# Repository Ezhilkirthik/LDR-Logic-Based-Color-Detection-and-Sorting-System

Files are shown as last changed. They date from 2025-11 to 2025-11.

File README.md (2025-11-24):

# LDR-Logic-Based-Color-Detection-and-Sorting-System
LDR Logic-Based Color Detection and Sorting System. Microcontroller-free automation using Analog &amp; Digital Electronics. 8-color detection (RGB, CMYK, White/Black) sorted by a servo motor controlled by Op-Amps, a Decoder, and 555 Timers (PWM). Low-cost, purely hardware solution.

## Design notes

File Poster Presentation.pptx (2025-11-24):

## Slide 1

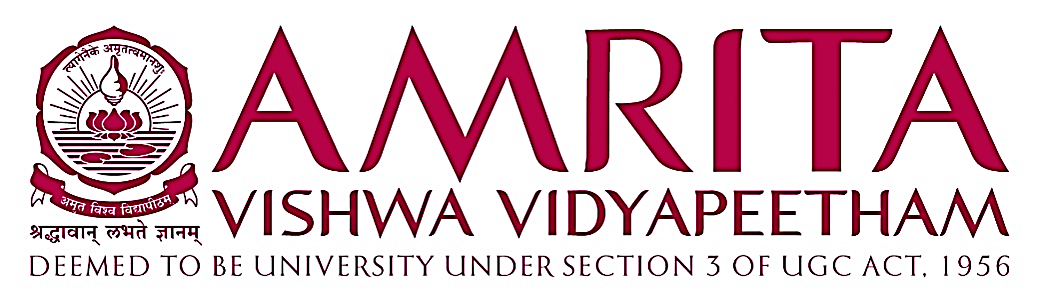
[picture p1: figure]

Batch ID - A2

Department of Electronics and Communication Engineering
Amrita School of Engineering, Coimbatore - 641112

B.Tech –ECE
23ECE381 Open Laboratory – I

LDR Logic-Based Color Detection and Sorting System
CB.EN.U4ECE23002 – Aathithya Pranav
CB.EN.U4ECE23004 – Adarsh B
CB.EN.U4ECE23016 – Ezhilkirthik M

Exhibition Date:11/10/25

PROBLEM STATEMENT

In industrial and laboratory environments, automated color detection and sorting of objects is often performed using microcontroller-based systems, which require programming, firmware, and complex software integration. Such reliance on microcontrollers can increase system cost, complexity, and power consumption, and may limit reliability in harsh or resource-constrained environments.
The challenge addressed in this project is to design and implement a real-time, microcontroller-free color detection and sorting system capable of accurately identifying and classifying multiple colors—specifically Red, Green, Blue, Cyan, Yellow, Magenta, and White—using only analog and digital electronic components. The system must operate autonomously, converting reflected light from objects on a conveyor belt into digital signals, and then driving mechanical actuators to sort objects into corresponding bins with precise timing, all without software or embedded programming.
This problem requires integrating optical sensing, signal conditioning, voltage comparison, digital logic decoding, and actuator control into a cohesive system that is reliable, low-cost, and capable of real-time operation.

CIRCUIT DIAGRAM /ALGORITHM

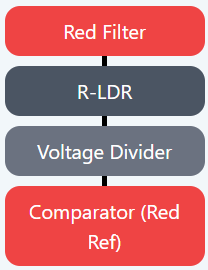
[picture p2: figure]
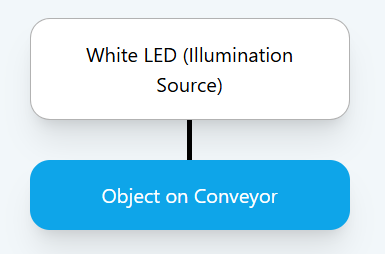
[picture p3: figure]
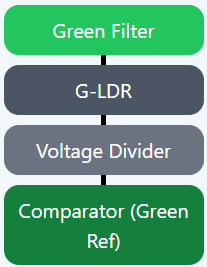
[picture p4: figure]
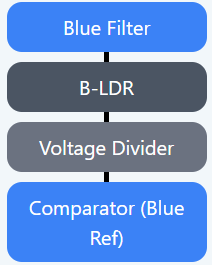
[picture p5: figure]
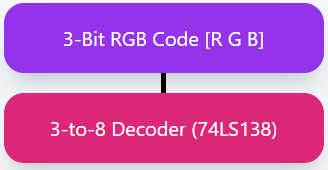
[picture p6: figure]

RESULTS

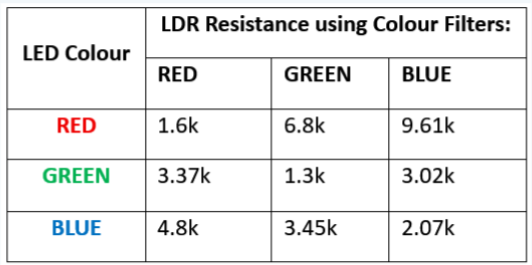
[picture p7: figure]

7 Segment Display Code | Blue | Green | Red | Output | Servo Rotation (°) | Pulse Width (ms)
0 | 0 | 0 | 0 | Black | 0 | 1
1 | 0 | 0 | 1 | Red | 22.5 | 1.125
2 | 0 | | 0 | Green | 45 | 1.25
3 | 0 | | 1 | Yellow | 67.5 | 1.375
4 | | 0 | 0 | Blue | 90 | 1.500
5 | 1 | 0 | 1 | Magenta | 112.5 | 1.625
6 | 1 | 1 | 0 | Cyan | 135 | 1.75
7 | 1 | 1 | 1 | White | 157.5 | 1.875

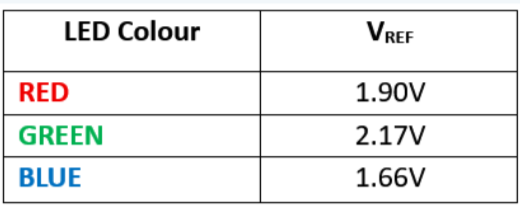
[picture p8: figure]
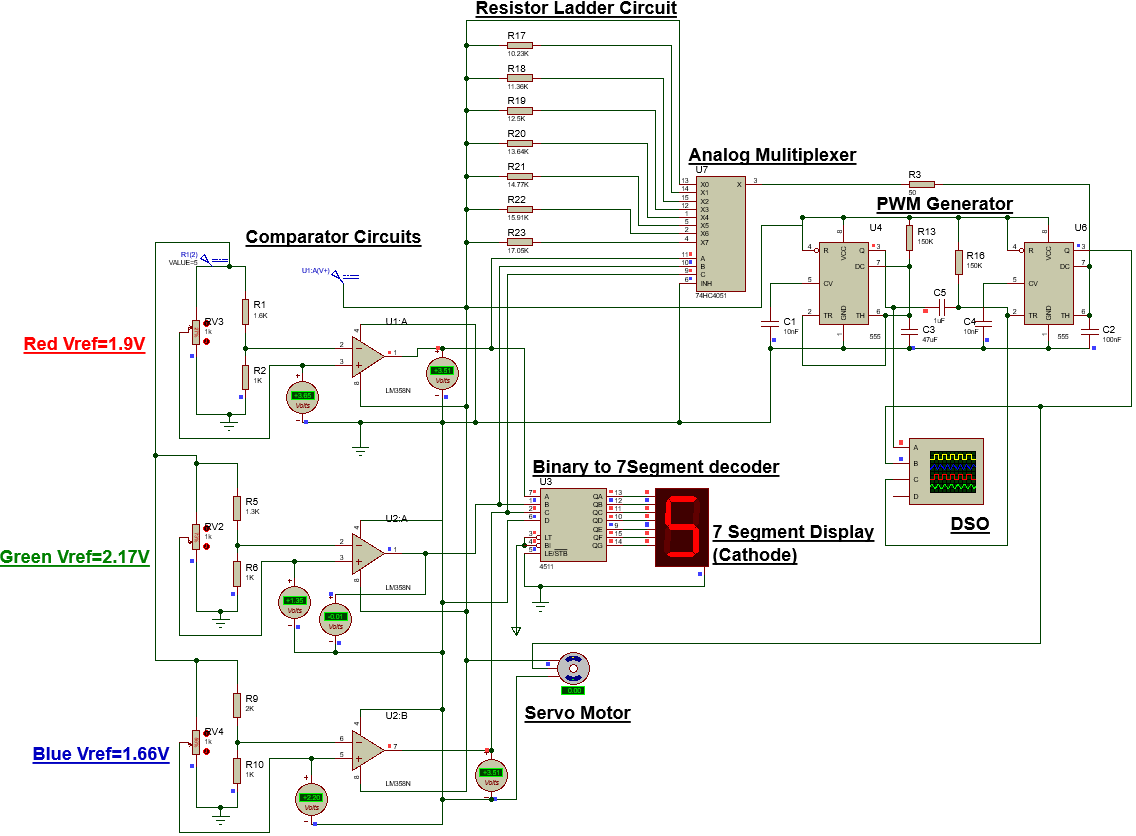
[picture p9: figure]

SIMULATION RESULTS

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
Servo Rotation (°) | Pulse Width (ms) | Resistor Values (R) | T = 1.1*(R)*C
0 | 1 | 0 | 1
22.5 | 1.125 | 10.23K | 1.122
45 | 1.25 | 11.36K | 1.248
67.5 | 1.375 | 12.5K | 1.375
90 | 1.500 | 13.64K | 1.5
112.5 | 1.625 | 14.77K | 1.628
135 | 1.75 | 15.91K | 1.749
157.5 | 1.875 | 17.05K | 1.8755

REFERENCES

[1] I. Mazumdar, R. Mondal, and S. Pal, “Design and development of a low cost colour sensor and its application in angular position control system of a stepper motor,” Int. J. Electron. Comput. Sci. Eng., vol. 2, no. 4, pp. 1241–1251, 2013.
[2] T. K. Binnar, D. D. Deoghare, P. N. Patil, and V. S. Kulkarni, “Designing of RGB color detector,” Int. J. Recent Dev. Eng. Technol., vol. 3, no. 2, p. 12, Aug. 2014.
[3] M. Petersen et al., “Conveyor line color object sorting using a monochrome camera, colored light and RGB filters,” in Proc. 23rd Annu. Hawaii Int. Conf. Educ., Honolulu, HI, USA, Jan. 4–7, 2025.
[4] A. Amhani and Z. Iqbal, “Automated color sensor system using LDR and RGB LEDs controlled by Arduino,” ARPN J. Eng. Appl. Sci., vol. 12, no. 19, pp. 5532–5535, Oct. 2017.
[5] H. Zhang and J. Li, "Design of a low-cost four-channel LDR-based line-follower sensor with transient and external interference compensations," Sensors, vol. 20, no. 4, p. 1111, 2020.
[6] Virtual Labs, IIT Roorkee, “Astable and Monostable Multivibrator,” Virtual Labs. [Online]. Available: https://ae-iitr.vlabs.ac.in/exp/astable-monostable-multivibrator/theory.html. [Accessed: Sep. 18, 2025].

APPROACH / DESIGN/ METHODOLOGY

- Illumination: A high-intensity white LED provides uniform lighting for objects on a motorized conveyor belt.
- Optical Sensing: Three LDRs behind Red, Green, and Blue filters detect reflected light to isolate RGB components.
- Analog Signal Conversion & Conditioning: LDR resistance changes are converted to analog voltages via voltage dividers.
- Threshold Detection: Comparators compare conditioned signals against reference voltages to produce digital outputs for each color.
- Digital Decoding: The 3-bit RGB code from comparators is decoded via a 3-to-8 line decoder to identify one of eight colors.
- Actuation & Sorting: A 180°servo with 1:2 gearing rotates the top platform 360° to align the correct bin with the conveyor for sorting.
- Timing Control: A 555 timer-based monostable circuit synchronizes object position with servo motor rotation.

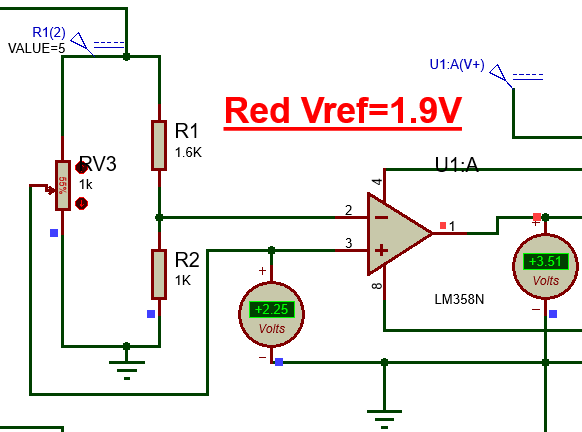
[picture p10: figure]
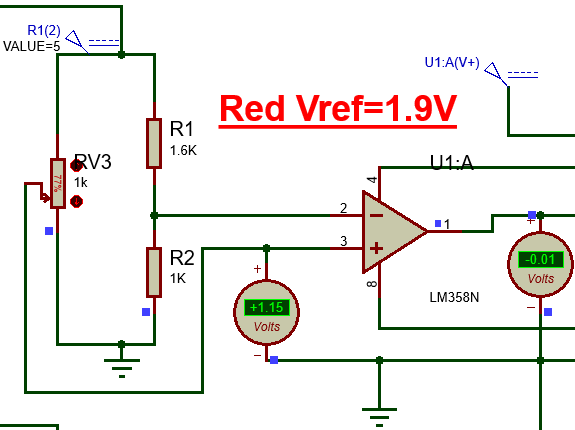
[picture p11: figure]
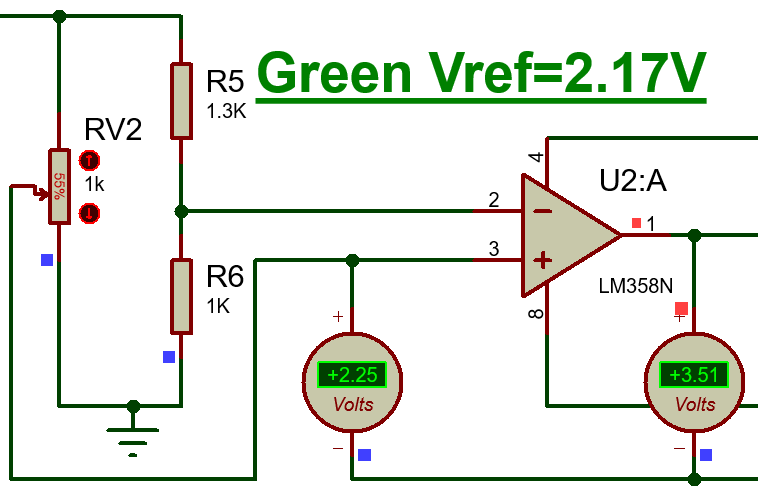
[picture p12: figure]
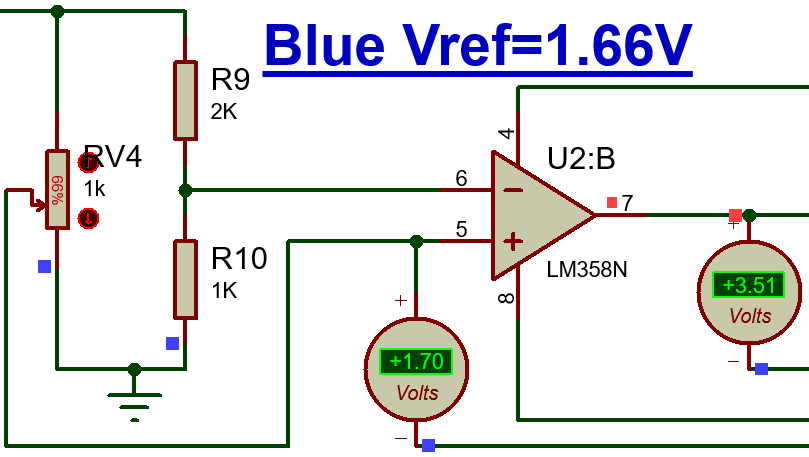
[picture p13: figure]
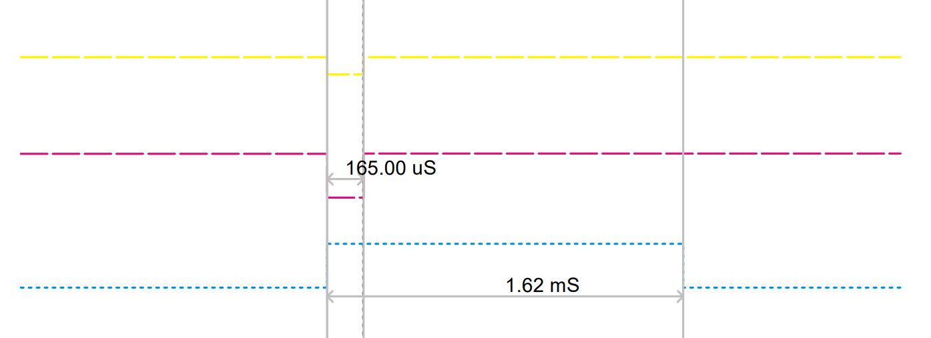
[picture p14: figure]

Monostable Trigger Input

Astable Output

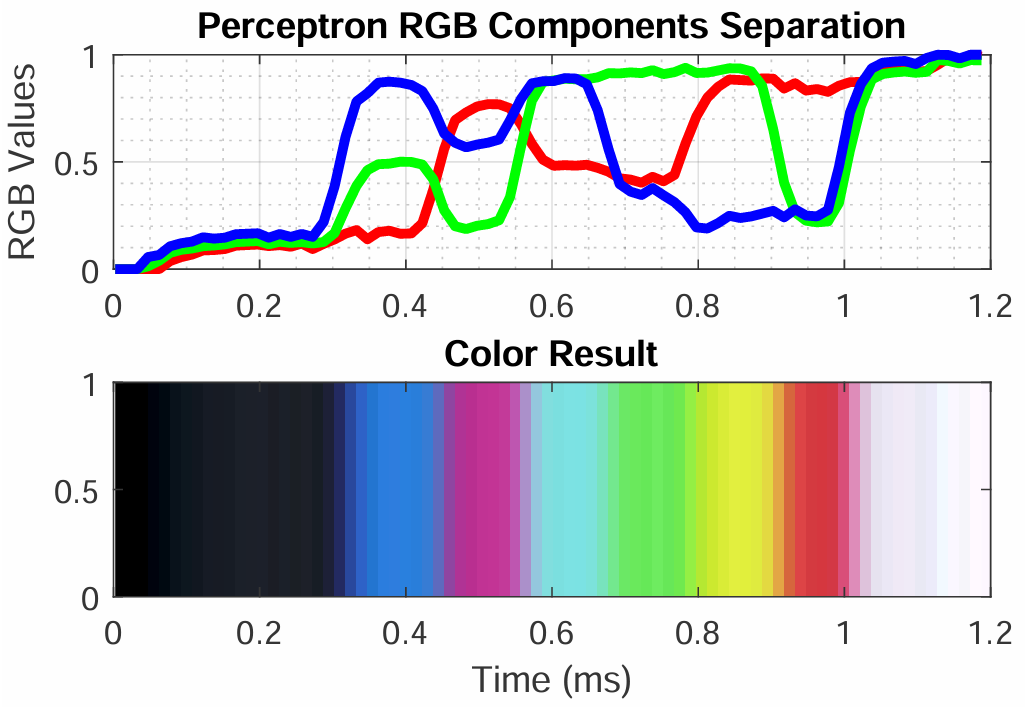
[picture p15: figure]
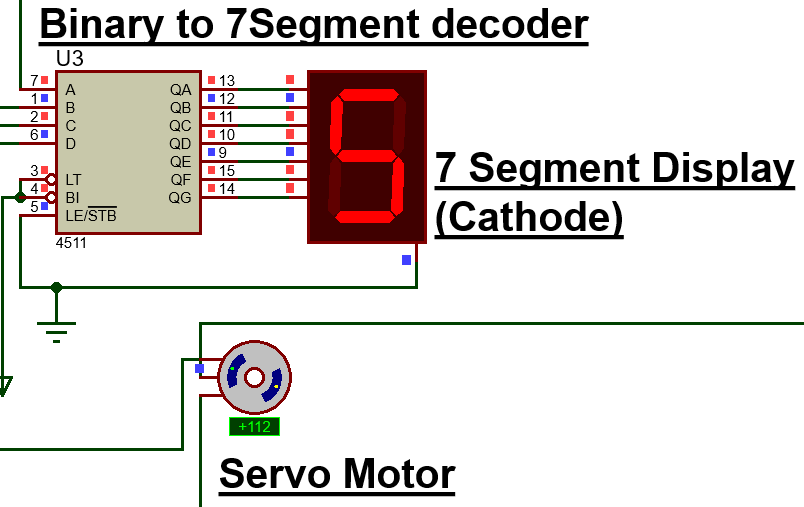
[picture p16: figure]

Servo Motor Pulse Input

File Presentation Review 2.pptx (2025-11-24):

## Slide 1

Amrita Vishwa Vidyapeetham
Department of Electronics and Communication Engineering

23ECE381 Open Lab- 1
Review -1

LDR Logic-Based Color Detection and Sorting System

Presented by :

Aathithya Pranav - CB.EN.U4ECE23002
Adarsh B - CB.EN.U4ECE23004
Ezhilkirthik M - CB.EN.U4ECE23016

Batch-A2

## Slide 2

Abstract

  - Detects and sorts 7 surface colors in real time using optics, LDRs, and digital logic.
  - White LED ensures consistent illumination for accurate color detection.
  - Three LDRs with RGB filters sense reflected light from the object.
  - Comparator circuits convert analog signals into a unique 3-bit digital code.
  - Decoder interprets the code to identify the color.
  - Servo motor directs the object to the correct sorting bin.
  - Entire system works on analog + digital components

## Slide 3

Literature Survey

Title of Paper/Website | Source | Inferences from this Paper/Website
Conveyor Line Color Object Sorting using A Monochrome Camera, Colored Light and RGB Filters | arXiv preprint, Feb. 2025 23rd Annual Hawaii International Conference on Education, Ja n . 4-7, 2025, Honolulu, Hawai | • Used color filters for accurate color segmentation. • Demonstrated object sorting on conveyor using basic vision + filter technique.
Designing of RGB Color Detector | Int. J. of Recent Development in Engineering and Technology, Aug. 2014 | • Gave insight into RGB sensor circuit design. • Helped identify how to calibrate colors using photodetectors.
Design and development of a low cost colour sensor and its application in angular position control system of a stepper motor | Int. J. of Electronics and Computer Science Engineering (IJECSE), 2013 | • Inspired microcontroller-free color sensing circuit idea. • Linked color detection with motor-based sorting system.

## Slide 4

Title of Paper/Website | Source | Inferences from this Paper/Website
Automated Color Sensor System Using LDR and RGB LEDs Controlled by Arduino Ahmad Amhani and Zaki Iqbal | Dept. of Engineering, American University of Ras Al Khaimah, UAE | • Demonstrated a simple yet reliable method using sequential RGB illumination with LDR response. • Emphasized calibration of color thresholds using analog voltage outputs and mapping logic.
WWCS – World’s Worst Color Sensor (Project14 Photonics Challenge) | Element14 Community Blog, Photonics Challenge | • Showed wavelength-based color separation technique and caturing all the reflected light from the object . • Inspired use of geometry and filter design for analog color capture.

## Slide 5

Block diagram

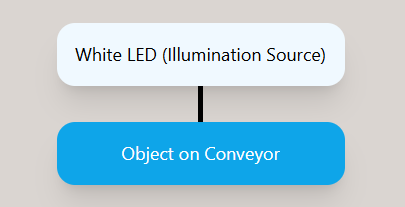
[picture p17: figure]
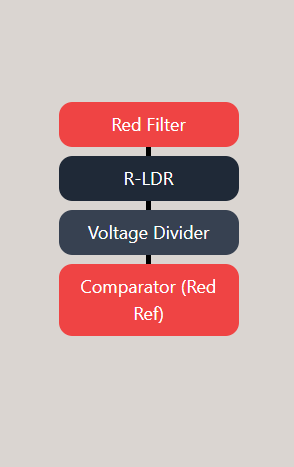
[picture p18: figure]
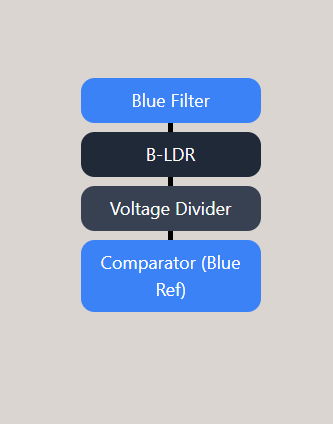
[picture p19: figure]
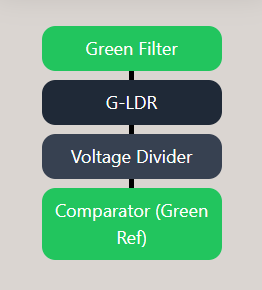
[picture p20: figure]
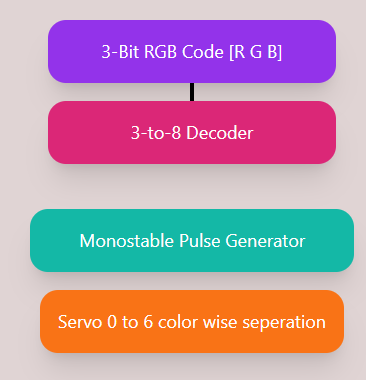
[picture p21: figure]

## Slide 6

Working Principle

1. Illumination & Reflection:
  - A single high-intensity White LED illuminates objects on a closed conveyor belt.
  - Each object reflects a specific combination of red, green, and blue light components based on its surface color.
2. Sensing & Processing:
  - Three LDRs behind RGB filters detect specific reflected light wavelengths (R: 600–700 nm, G: 500–600 nm, B: 400–500 nm).
  - LDR resistance varies with light intensity, generating color-specific signals.
  - Voltage divider circuits convert resistance to analog voltage.
3. Digital Conversion & Decoding:
  - Comparator circuits compare analog voltages with reference levels and output binary HIGH (1) or LOW (0).
  - The three outputs (R, G, B) form a 3-bit digital code (e.g., 001 = Blue, 011 = Cyan).
  - This code is input to a 3-to-8 decoder, which activates one unique output corresponding to the detected color.

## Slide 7

Graphs from Research Paper

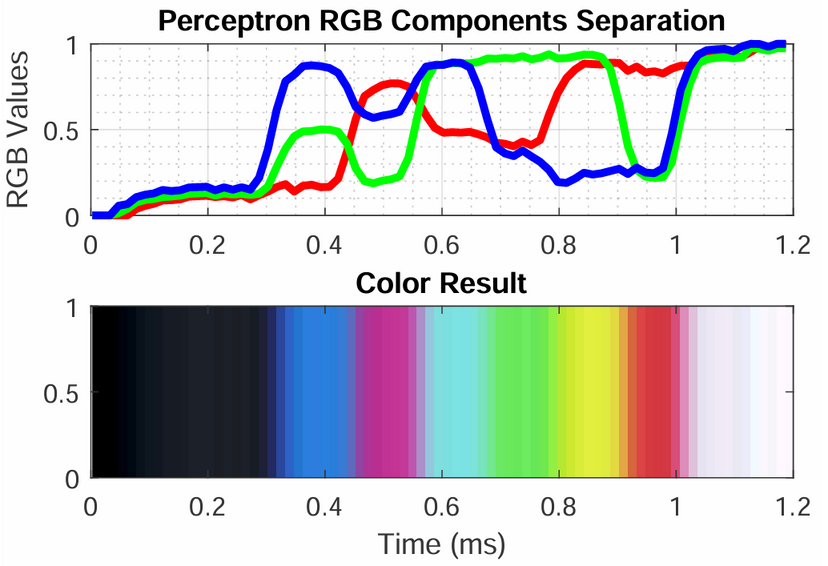
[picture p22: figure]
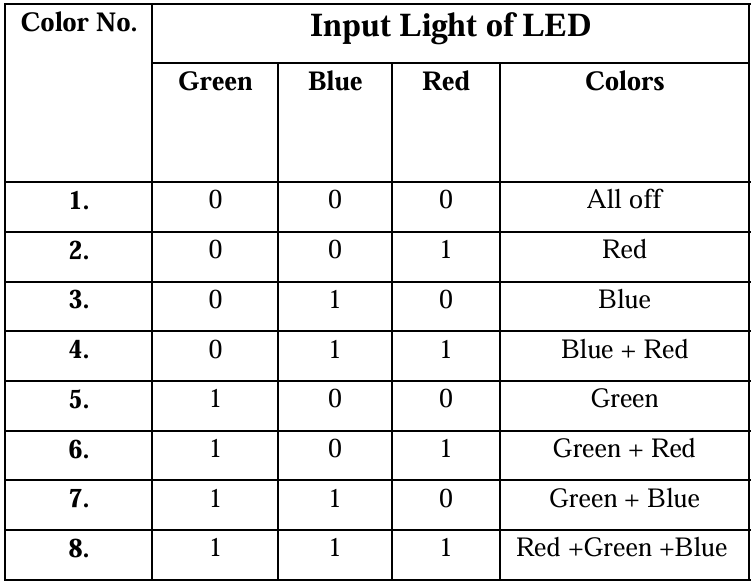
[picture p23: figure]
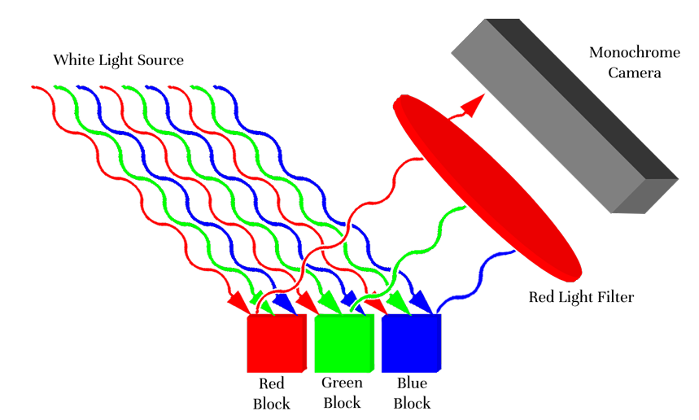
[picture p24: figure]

LDR

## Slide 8

Inference

  - Real-time color identification and sorting without microcontrollers or programming.
  - Operates entirely on analog and digital electronics for a cost-effective solution.
  - LDRs with RGB filters detect reflected light from objects on a conveyor belt.
  - Light signals converted to voltage, processed via op-amps and comparators.
  - Signals translated into a 3-bit binary RGB code for color representation.
  - 3-to-8 decoder activates actuators to sort objects by color.
  - 555 timer (monostable multivibrator) ensures precise sorting timing.
  - Capable of identifying up to 7 distinct colors.

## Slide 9

Reference

[1] I. Mazumdar, R. Mondal, and S. Pal, “Design and development of a low cost colour sensor and its application in angular position control system of a stepper motor,” Int. J. Electron. Comput. Sci. Eng. (IJECSE), vol. 2, no. 4, pp. 1241–1251, 2013.
[2] T. K. Binnar, D. D. Deoghare, P. N. Patil, and V. S. Kulkarni, “Designing of RGB Color Detector,” Int. J. Recent Dev. Eng. Technol., vol. 3, no. 2, p. 12, Aug. 2014.
[3] M. Petersen, B. Lakenen, K. Chavan, P. Waghmare, A. Sergeyev, and N. Rawashdeh, “Conveyor line color object sorting using a monochrome camera, colored light and RGB filters,” in Proc. 23rd Annu. Hawaii Int. Conf. Educ., Honolulu, HI, USA, Jan. 4–7, 2025.
[4] A. Amhani and Z. Iqbal, “Automated color sensor system using LDR and RGB LEDs controlled by Arduino,” ARPN J. Eng. Appl. Sci., vol. 12, no. 19, pp. 5532–5535, Oct. 2017.
[5] D. P. Martin, “WWCS — World’s Worst Color Sensor — Project14 Photonics Challenge,” element14 Community, Jul. 2, 2018. [Online]. Available: https://community.element14.com/challenges-projects/project14/photonics/b/blog/posts/wwcs---world-s-worst-color-sensor---project-14-photonics-challenge. [Accessed: Jul. 19, 2025].

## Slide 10

Amrita Vishwa Vidyapeetham
Department of Electronics and Communication Engineering

Thank
You

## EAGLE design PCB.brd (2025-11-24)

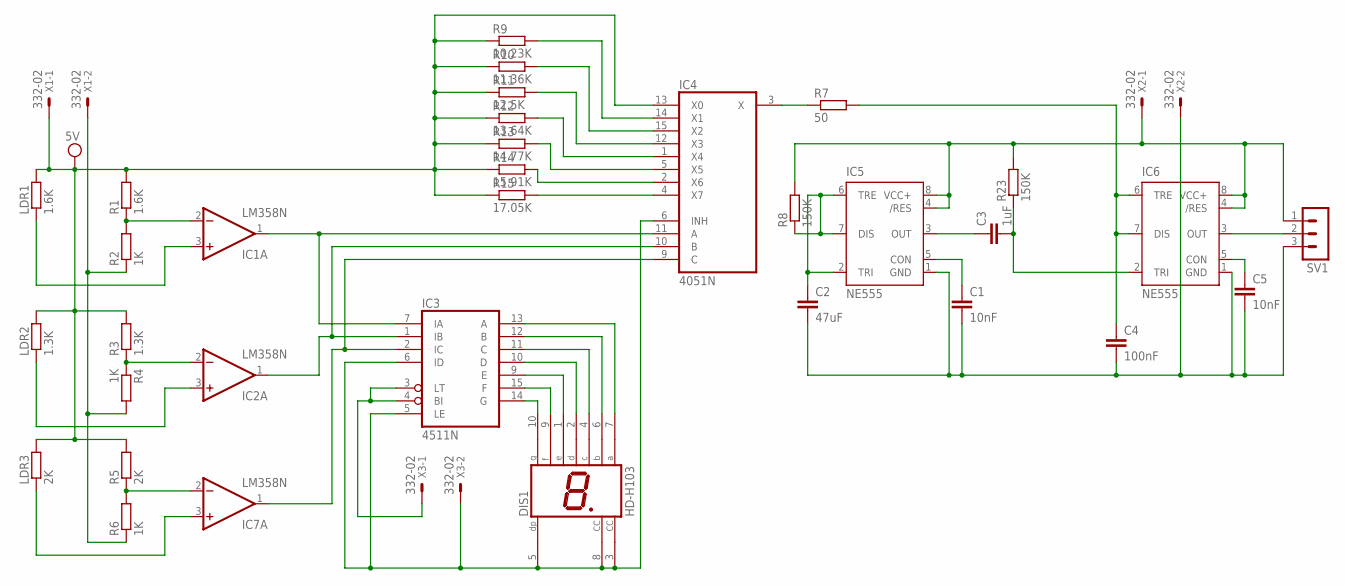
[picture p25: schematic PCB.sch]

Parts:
C1, C5: 10nF; C2.5-2
C2: 47uF; C2.5-2
C3: 1uF; C2.5-2
C4: 100nF; C2.5-2
DIS1: HD-H103; HDSP-M
IC1, IC2, IC7: LM358N; DIL08
IC3: 4511N; DIL16
IC4: 4051N; DIL16
IC5, IC6: NE555; DIL-08
LDR1: 1.6K; 0207/10
LDR2: 1.3K; 0207/10
LDR3: 2K; 0207/10
R1: 1.6K; 0207/10
R2, R4, R6: 1K; 0207/10
R3: 1.3K; 0207/10
R5: 2K; 0207/10
R7: 50; 0207/10
R8, R23: 150K; 0207/10
R9: 10.23K; 0207/10
R10: 11.36K; 0207/10
R11: 12.5K; 0207/10
R12: 13.64K; 0207/10
R13: 14.77K; 0207/10
R14: 15.91K; 0207/10
R15: 17.05K; 0207/10
SV1: MA03-1
X1, X2, X3: 332-02

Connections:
GND: IC4.8 (GND)
unnamed: IC1.2 (-IN), R1.1, R2.2
unnamed: IC2.2 (-IN), R3.1, R4.1
unnamed: IC7.2 (-IN), R5.1, R6.2
unnamed: DIS1.10 (G), IC3.14 (G)
unnamed: DIS1.9 (F), IC3.15 (F)
unnamed: IC1.3 (+IN), LDR1.1
unnamed: IC2.3 (+IN), LDR2.1
unnamed: IC7.3 (+IN), LDR3.1
unnamed: IC1.1 (OUT), IC3.7 (IA), IC4.11 (A)
unnamed: IC2.1 (OUT), IC3.1 (IB), IC4.10 (B)
unnamed: IC3.2 (IC), IC4.9 (C), IC7.1 (OUT)
unnamed: IC4.4 (X7), R15.2
unnamed: DIS1.1 (E), IC3.9 (E)
unnamed: DIS1.2 (D), IC3.10 (D)
unnamed: DIS1.4 (C), IC3.11 (C)
unnamed: DIS1.6 (B), IC3.12 (B)
unnamed: DIS1.7 (A), IC3.13 (A)
unnamed: DIS1.3 (CC), DIS1.5 (DP), DIS1.8 (CC), IC3.5 (LE), IC3.6 (ID), IC4.6 (INH), X3.2
unnamed: IC4.2 (X6), R14.2
unnamed: IC4.5 (X5), R13.2
unnamed: IC4.1 (X4), R12.2
unnamed: IC4.12 (X3), R11.2
unnamed: IC4.15 (X2), R10.2
unnamed: IC4.14 (X1), R9.2
unnamed: IC4.3 (X), R7.1
unnamed: C1.1, IC5.5 (CON)
unnamed: C3.1, IC5.3 (OUT)
unnamed: C3.2, IC6.2 (TRI), R23.1
unnamed: C2.1, IC5.2 (TRI), IC5.6 (TRE), IC5.7 (DIS), R8.1
unnamed: C4.1, IC6.6 (TRE), IC6.7 (DIS), R7.2
unnamed: C5.1, IC6.5 (CON)
unnamed: IC6.3 (OUT), SV1.2
unnamed: C1.2, C2.2, C4.2, C5.2, IC5.1 (GND), IC6.1 (GND), SV1.3, X2.2
unnamed: IC3.3 (LT), IC3.4 (BI), X3.1
unnamed: R2.1, R4.2, R6.1, X1.2
unnamed: IC5.4 (/RES), IC5.8 (VCC+), IC6.4 (/RES), IC6.8 (VCC+), R8.2, R23.2, SV1.1, X2.1
V+: IC1.8 (V+), IC2.8 (V+), IC7.8 (V+)
V-: IC1.4 (V-), IC2.4 (V-), IC7.4 (V-)
VCC: IC4.13 (X0), IC4.16 (VCC), LDR1.2, LDR2.2, LDR3.2, R1.2, R3.2, R5.2, R9.1, R10.1, R11.1, R12.1, R13.1, R14.1, R15.1, X1.1
VDD: IC3.16 (VDD)
VEE: IC4.7 (VEE)
VSS: IC3.8 (VSS)

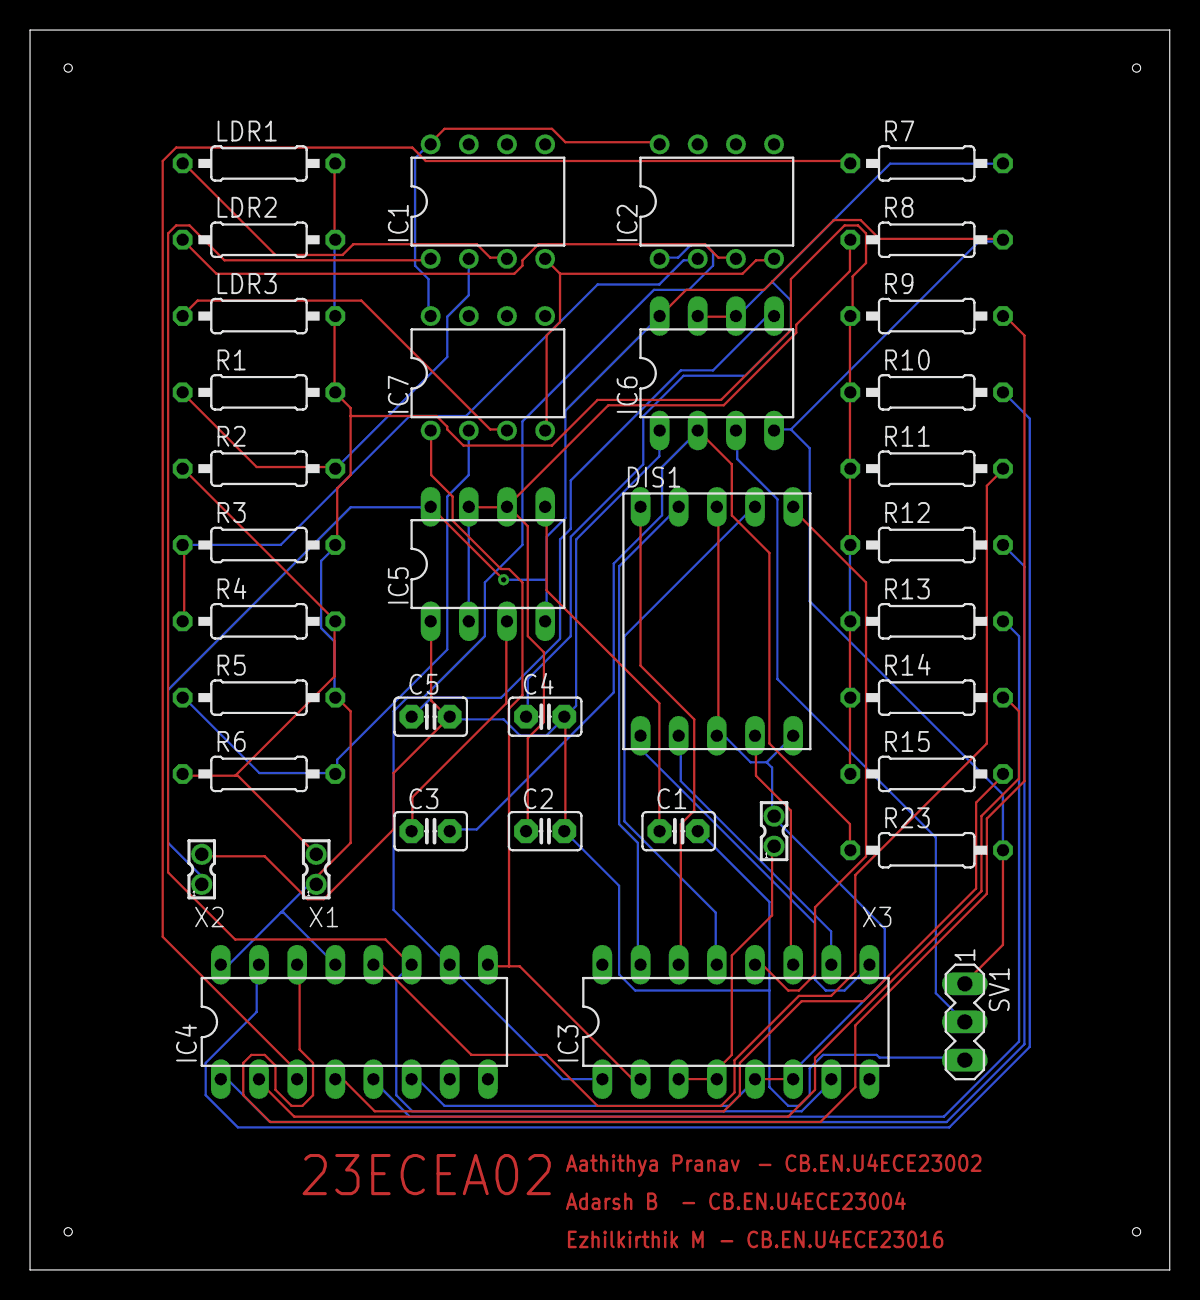
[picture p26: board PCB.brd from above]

Board: 2 copper layers, 75.9 x 82.5 mm, 36 parts (0 on the bottom side), 39 nets.
